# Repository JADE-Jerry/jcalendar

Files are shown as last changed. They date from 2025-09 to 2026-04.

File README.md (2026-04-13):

# J-Calendar
墨水屏日历，采用三色4.2寸墨水屏，展示基本月历信息，支持农历、公共假期、倒计日、天气（实时天气、每日天气）、课程表展示。<br>
项目以低难度、低成本的方式，方便爱好者实现属于自己的低功耗月历。<br>
<br>
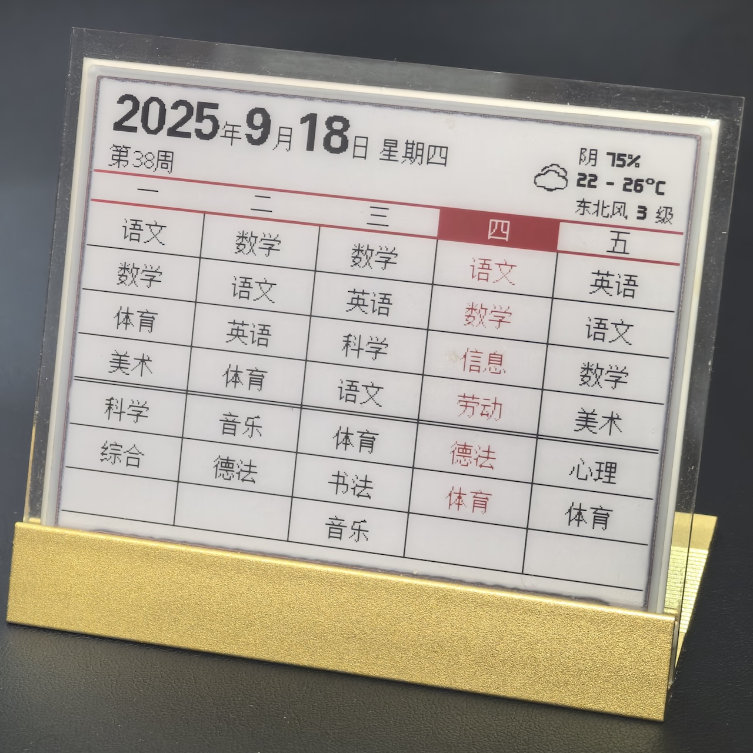
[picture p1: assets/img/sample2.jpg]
<br>
Bilibili连接：https://www.bilibili.com/video/BV1wHDhYoE3G/<br>
注：固件仅供个人下载免费使用，禁止商用。

## Prepare & Meterial
1. esp32开发板(建议lolin32 lite,其他esp32开发板亦可)<br>
2. 4.2寸三色墨水屏(400*300)。
3. 通用墨水屏驱动板。
4. 锂电池,需要做ph2.0接头，建议购买带保护板的电池。(推荐603048, 900mah)
5. 金属底座亚克力台卡,95*80mm。
6. 轻触开关,(12\*12\*7.3,带键帽)
7. 工具:电烙铁、电线若干。

## Manufacture Guide:
1. 开发板接线<br>
    * 墨水屏驱动板
        * Busy->4
        * RST->16
        * DC->17
        * CS->5
        * SCK->18
        * SDA->23
        * GND->GND
        * VCC->3V
    * 其他
        * 按钮->(PIN_14, GND)
        * LED->22(板载)
        * 电池ADC->32
2. 三色墨水屏排线插入时注意针脚方向,屏幕排线和驱动板排线1号针脚均是悬空,注意对齐。
3. 电池接口需要是ph2.0,且注意正负极(开发板上有标注),如果电池的正负极反了,可以用镊子调整电池插头。
    1. 可选：电池电压检测电路，需要通过两个相同的大电阻（建议500K以上）串联，通过分压进行检测电池电压。如图
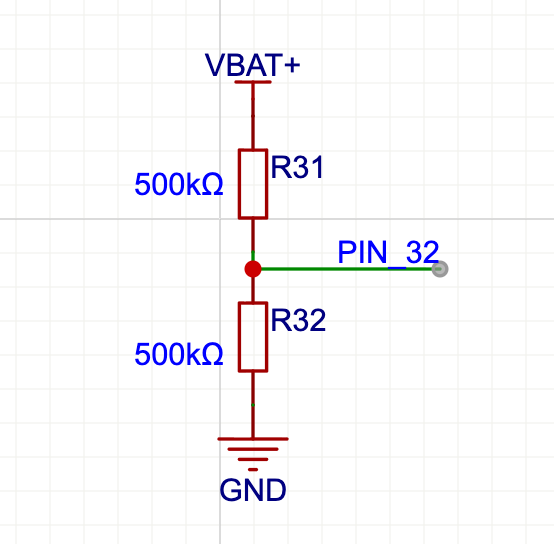
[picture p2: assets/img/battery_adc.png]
    <br>
4. 烧录固件<br>
    使用ESP32的烧录工具flash_download_tool烧录固件. [Flash Download Tools](https://www.espressif.com/en/support/download/other-tools?keys=flash+download+tools)
    1. 选择烧录的文件和烧录地址（bootloader.bin与partitions.bin烧录过一次后，就不需要重复烧录了）
    2. 选择Flash的配置信息
    3. 选择连接的串口以及波特率（波特率可以根据实际情况调整）
    4. 擦除Flash。
    5. 开始烧录。<br>
    <span style="color:red">注：文件前面一定要打勾，否则不会刷进flash的！！！</span><br>
    （参考下图）<br>
    
5. 安装盒，3D打印，用PLA或ABS均可。[E-ink box2 v22.3mf](./assets/file/E-ink%20box2%20v22.3mf)

## Button Operation Guide:
1. **单点**  
    如果处在休眠中,唤醒系统,并刷新月历。
    如果处在运行中,强制刷新/切换日历。
    如果处在配置中,不做任何处理。
2. **双击**  
    系统正常运行中,双击进入系统配置。(并强制停止WIFI相关操作,如获取天气。)
    系统配置状态中,双击重启系统。
3. **长按**  
    系统运行中,长按清除配置信息(WIFI密钥除外)和缓存,并重启。

## LED Indicator: 
(板载LED,PIN-22)
1. 快闪: LED每秒闪约两次，系统启动中(正在连接WIFI)
2. 常亮: WIFI连接完成。
3. 慢闪: LED每两秒闪一次，WIFI连接失败（10秒钟后休眠）。
4. 三短闪一长灭: 系统配置中。（3分钟后超时休眠）
5. 熄灭: 系统休眠。

## Web Config Guide:
通过在开机状态下(LED常亮)双击,即可进入配置状态,这时系统会生成一个名为J-Calendar的ap,默认密码为:password。(默认超时时间为180秒)
连接上ap后会直接弹出配置页面。(或者直接通过浏览器输入地址 http://192.168.4.1进入)。
配置页面:
1. Config Wifi. Wifi配置  
    进入配置wifi页面,选择搜索到的ap,并输入密码,并保存。
2. Setup. 系统配置  
    * 周首日:
        * 0: 周日(默认); 1: 周一;
    * 和风天气:
        * 和风天气Host：输入在和风天气Host。（例如：******.re.qweatherapi.com, 具体值在自己的和风天气控制台可以查到<br>
        * 输入和风天气的API Key：输入和风天气Key。（如果Key置空,天气将不会被刷新。）<br>
        * 天气类型：0:每日天气（默认，每天凌晨刷新一次）; 1: 实时天气(每两个小时刷新一次天气)<br>
        * 位置ID：城市id或者经纬度 例1: 101010100 例2: 116.41,39.92 <br>
        [城市id列表](./assets/file/China-City-List-latest.csv) <br>
    * 倒数日:<br>输入倒数日名称和日期,名称不能超过4个中文字符,时间以yyyyMMdd的格式填入。配置正确的话,日历每天会显示倒数“距****还有**天”。如果倒数日名称为空,系统将不显示倒数日信息。
    * 日期Tag:<br>
        1. 输入格式，yyyyMMddx，yyyy为年，每年显示设为0000，MM为月份，每月显示设为00，dd为日期，x为tag的图标（a:书签；b：金钱；c：笑脸；d：警告）。例如：00000015b，每年每月15日旁边显示$符号；00000312a，每年3月12日，显示书签符号。
        2. 最多可以设置三个tag，中间以分号隔开。例如：00000015b;00000312a
    * 课程表:<br>
        输入格式，分多段，每段用“；”隔开。
        1. 课程数段。"000"，三位数字，分别代表上午、下午、晚上课程数，不可省略。如：“430”，代表上午4课，下午三课，晚上无课。
        2. 每日课程（多段）。首位为星期数，后接当日的课程，以“，”分隔。如：“二,数学,语文,英语,体育,音乐,德法,”，表示周二的课程为数学、语文...等。
        3. 样例: 430;一,语文,数学,体育,美术,科学,综合;二,数学,语文,英语,体育,音乐,德法;三,数学,英语,科学,语文,体育,书法,音乐;四,语文,数学,信息,劳动,德法,体育;五,英语,语文,数学,美术,心理,体育;
        4. 注意：分隔用的“,”“;”，必须为英文符号，不可用中文符号。
    * 保存配置后，系统自动重启。
3. Update. OTA升级  
    此项需要在浏览器内完成,通过ip地址访问配置页面,然后进入Update,选择固件文件后上传,等待。刷新完成后,页面会有成功提示。
4. Restart. 重启  
    在所有配置完后,需要重启生效。(也可以在配置状态下,双击按钮重启)
5. Info. 系统信息
    可以监控系统的硬件情况,也可以在里面清除配置的Wifi密钥。
6. Exit. 退出  
    退出配置状态。

## Q & A
1. Q: 刷完机后，如何配置？启动流程是如何的？<br>
A: 需要在系统运行状态下（状态灯常亮或慢闪时）双击按键，即可进入配置状态。LED灯变成三短闪一长灭时说明进入配置状态了。
2. Q: 刷完机后，没有反应该如何处理？<br>
A: 观察22针脚的LED是否点亮，有闪烁说明固件已经刷入，如果没有闪烁可以尝试点击重置按钮重启，或者拔掉电源线和usb线，重插来重启。此外，还可使用串口工具通过usb的com口获取启动日志来进一步确认故障原因。
3. Q: 可以支持哪种屏？<br>
A: 仅4.2寸三色屏(目前仅支持黑白红,将来支持黑白黄)。
4. Q: 我使用的屏应该烧录哪个固件？<br>
A: 从经验上预估，大部分比较新一些的选1680，新一点的拆机屏选z98。SES的拆机屏选z21，如果是非常老的屏，选z15。实在不行的话，三个固件都刷一遍试试。<br>
明确的丝印对应如下：<br>
    |丝印|固件|
    |-----|-----|
    |P420010|1680|
    |E042A43-A0|z98|
    |A13600**|z21|
5. Q: 使用flash download tool刷新固件时，报错，连接串口失败。<br>
A: 1. 检查USB线连接是否正常。 <br>2. app的串口下拉框里是否检测到COM口。 <br>3. 把其他串口工具关闭，防止占用COM口。
6. Q: 刷新固件的过程中提示报错。<br>
A: 1. 换根质量较好的或短一些的USB线，或换个USB口插入。 <br>2. 可以将刷新的波特率降低一点，如选择速率低一点的115200。
7. Q: 刷新固件后，需要重新配置吗？<br>
A: 仅刷新app固件后，配置是保留的，所以，无需重新配置。如果刷新了分区表partition.bin，会将esp的nvs区刷新，这时候需要重新配置。
8. Q: 填入和风天气的API Key和位置ID后，没有成功获取天气信息。<br>
A: 2025年3月1日后注册的和风天气账户有API Host限制，请下载1.0.25以后版本，在配置时配置API Host信息。
8. Q: 如何切换日历和课程表显示？<br>
A: 在系统运行状态下(状态灯常亮)，单击按键，稍等即可切换课程表的展示。
9. Q: 充一次电能使用多久？<br>
A: 这个取决于选用的电池和使用场景，以及开发板的质量。正常情况下休眠的电流为120ua左右，刷新一次需要1.6mah。以900mah的电池、每日刷新一次举例，理论上大概可以待机半年。
10. Q: 为何我的日历待机时间很短？<br>
A: 可能是开发板或驱动板的质量问题，实际发现有些板子休眠功耗能达2ma，这会极大影响待机时长。另外，由于电池容量的虚标，待机时长与理论计算值也有较大偏差。建议，增加电池测量电路，及时显示电池电量情况。

## Releases
### 1.1.9
* Fix: z98等版本编译问题。
### 1.1.8
* Fix: 农历日历错误。
### 1.1.7
* Fix: 内置节日信息未展现。
### 1.1.6
* Fix: 课程表页面星期显示位置不当。
### 1.1.5
* Fix: 将1680驱动加入GxEPD2,并放入项目的lib目录。 
### 1.1.4
* Refine: 电池检测、功耗优化
* New: 增加1680驱动版本
### 1.1.3
* Fix: some bugs.
### 1.1.2
* Refine: 功耗
### 1.1.1
* New Featue: 增加对电池的测量和显示。
### 1.1.0
* New Feature: 课程表。
* Refine: 对针脚统一配置。
* Fix: some bugs.
### 1.0.27
* Fix: 闰月错误。（bug from nongli lib）
### 1.0.26
* Refine: 显示当前为第**周。（国际标准（ISO 8601）‌：以周一作为每周起始日）
### 1.0.25
* Fix: 和风天气api变更，需要输入API Host（在配置页面增加配置项）
### 1.0.24
* Refine: 配置页面location约束改为64长度，允许输入经纬度设置天气位置（e.g. 116.41,39.92）
### 1.0.23
* Refine: 修改和风天气请求url。
* Fix: bug(获取holiday返回码)。
### 1.0.22
* 项目开源：此项目使用GNU General Public License v3.0许可证授权。详情请参阅LICENSE文件。
* Refine：农历计算功能移出。（农历功能作为独立库，以MIT协议开源）
### 1.0.21
* Fix: bug (wrong background color of calender header).
### 1.0.20
* Fix: bugs.
### 1.0.19
* New: 假日信息通过网络API获取。
* Refine: 由于esp32内置时钟的误差，会有可能唤醒的时间不准确，同时，由于处于午夜0点左右，导致提前刷新或在刷新期间切换日期，导致日期显示不准确。处理方式：计时器唤醒的情况下，23:50以后不刷新直接休眠，等待至0点以后唤醒刷新。
### 1.0.18
* Fix: 修正Wifi连接失败后，同步时间导致系统时间错误。
### 1.0.17
* Refine: 如果wifi连接失败，等待10s再休眠，并增加LED慢闪作为指示。（在这时间段内供用户进行双击打开配置状态）
* Fix: 修正倒数日名称显示不足的问题。
### 1.0.16
* New Feature: UI调整，新增今日农历日期的展现。
### 1.0.15
* Fix: 编译异常。
### 1.0.14
* Fix: bug(假日颜色不正确), 增加显示假日和调休icon(日历右上角)。
### 1.0.13
* Fix: bugs.
### 1.0.12
* 新功能：增加设置每周首日，默认首日为周日。
### 1.0.11
* 优化：补充部分公历&农历节日
### 1.0.10
* 新功能：增加日期Tag（通过配置页面进行配置）
### 1.0.9
* 优化：
    1. 统一每日天气与实时天气的布局。
    2. 增加时间容错性，当同步网络时间失败的时候，使用天气api的更新时间。
* 新功能：增加节日显示（元旦、劳动节、国庆节）
### 1.0.8
* 优化显示：加粗当前日期框；不再使用局刷，全部改为全屏刷新（提高显示的清晰度，兼容不支持局部刷新的三色屏）。
* 预置2025年公休假信息。
### 1.0.7
* 增加24节气显示。修复部分bug。
### 1.0.6
* 增加天气模式--*每日天气*（默认配置），每天刷新一次。（增加月历待机时长。部分不支持局刷的屏可以选择这个模式。）
### 1.0.5 
* 增加强制刷新处理(单击按钮)。
* 修复日历功能、修复日历字典数据
* 修复部分bug。
### 1.0.4<br>
* 增加倒计日功能
* 修复部分bug。
### 1.0.3
* 基本功能
* 功耗优化等

## License
此项目使用GNU General Public License v3.0许可证授权。详情请参阅LICENSE文件。

### ★★★固件还不错，支持一下★★★

<br>

感谢大家的赞助：
\*1，\*翔，\*菜，\*华，\*名，\*波, \*人, G\*n。

## Reference:
1. \<WEMOS LOLIN32簡介\> https://swf.com.tw/?p=1331&cpage=1
2. \<GxEPD2\> https://github.com/ZinggJM/GxEPD2
3. \<U8g2_for_Adafruit_GFX\> https://github.com/olikraus/U8g2_for_Adafruit_GFX
4. \<和风天气\> https://dev.qweather.com/docs/api/weather/weather-now/
<br>
 Copyright © 2023-2026. All Rights Reserved.

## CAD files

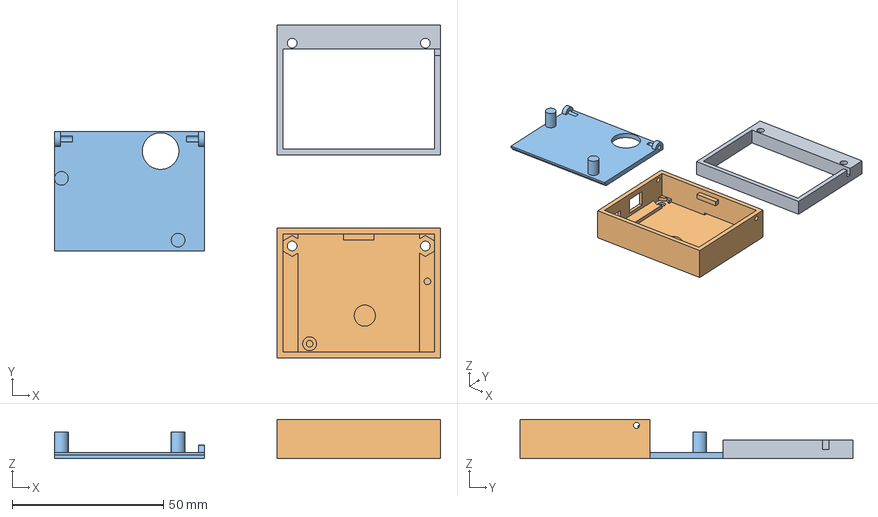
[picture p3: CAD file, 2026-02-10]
assets/file/E-ink box2 v22.3mf
127.5 x 110.0 x 13.0 mm
零部件3
零部件1
实体1.stl

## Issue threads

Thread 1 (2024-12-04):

关于自动刷新的问题

SzetoFZ, 2024-12-04:
由于开启了自动两小时的自动刷新，当正在刷新时出现无法正常联网的情况下会自动随机刷新一个任何时间的日期，能不能修改一下当刷新时无法联网的时可以保留之前的日期的功能

JADE-Jerry, 2024-12-04:
你刷的是哪个版本。最新的版本已经处理过这个问题，如果无法联网的话，时间会根据单片机内部时间来计算当下时间，但是会有大概每天20秒左右的误差。

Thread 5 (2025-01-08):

1.0.14，刷完z98固件，power on后立即power off，屏幕没变化。

ahptc6188, 2025-01-08:
09:47:39.202 -> Calendar Show Time: 2006-05-26 16:25:28
09:47:39.202 -> [Task] screen update begin...
09:47:39.293 -> Invalid countdown-day parameters.
**09:47:39.293 -> _PowerOn : 25
09:47:39.466 -> _Update_Full : 1
09:47:39.466 -> _PowerOff : 1
09:47:39.466 -> _PowerOff : 1**
09:47:39.466 -> [Task] screen update end...
09:47:39.507 -> [   422][E][Preferences.cpp:483] getString(): nvs_get_str len fail: QWEATHER_KEY NOT_FOUND

JADE-Jerry, 2025-01-08:
要么是屏幕连接不好，要么是驱动不对，建议换固件。

Closed 2025-01-08.

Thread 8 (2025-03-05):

通电或配置时，频繁自动重启

funcc, 2025-03-05:
刚通电或进行配置时，板子经常频繁重启，多的时候半小时都在不停重启。用串口连上看，提示
***********************
      J-Calendar
    version: 1.0.22
***********************

Copyright © 2022-2025 JADE Software Co., Ltd. All Rights Reserved.

Wm begin...
*wm:AutoConnect
*wm:Connecting to SAVED AP: xxxx
*wm:AutoConnect: SUCCESS
*wm:STA IP Address: 192.168.0.178
Connect OK.
[Task] get weather begin...
Weather Type: 0
               decompressed 1666 bytes
[Task] get weather end...
SNTP OK.
Now: 2025-03-05 22:52:14
Wifi closed after data fetch.
System Time: 2025-03-05 22:52:14
                                Calendar Show Time: 2025-03-05 22:52:14
                                                                       [Task] screen update begin...
Busy Timeout!
_PowerOn : 40001203

Error reading data on serial port:
  Access is denied.

funcc, 2025-03-06:
可能是屏有问题，虽然有时能正常。换块屏就没问题了。

Closed 2025-03-06.

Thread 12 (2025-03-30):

ESP32-C3编译报错

TopPeak-Xiang, 2025-03-30:
# ESP32-C3编译报错
> 在使用源文件中自带ESP32 C3的环境进行编译下载时出现了下面的问题，此问题出现在API.hpp文件中：

```c++
no matching function for call to 'ArduinoUZlib::decompress(uint8_t*, uint32_t, uint8_t*&, size_t&)'
```

> 下面是输出的信息：

```c++
*  正在执行任务: C:\Users\Cheems\.platformio\penv\Scripts\platformio.exe run --target upload --environment esp32c3

Processing esp32c3 (platform: espressif32; board: esp32-c3-devkitm-1; framework: arduino)
---------------------------------------------------------------------------------------------------------------------------------------
Verbose mode can be enabled via `-v, --verbose` option
CONFIGURATION: https://docs.platformio.org/page/boards/espressif32/dfrobot_beetle_esp32c3.html
PLATFORM: Espressif 32 (6.10.0) > DFRobot Beetle ESP32-C3
HARDWARE: ESP32C3 160MHz, 320KB RAM, 4MB Flash
DEBUG: Current (cmsis-dap) External (cmsis-dap, esp-bridge, esp-builtin, esp-prog, iot-bus-jtag, jlink, minimodule, olimex-arm-usb-ocd, olimex-arm-usb-ocd-h, olimex-arm-usb-tiny-h, olimex-jtag-tiny, tumpa)
PACKAGES:
 - framework-arduinoespressif32 @ 3.20017.241212+sha.dcc1105b
 - tool-esptoolpy @ 1.40501.0 (4.5.1)
 - tool-mkfatfs @ 2.0.1
 - tool-mklittlefs @ 1.203.210628 (2.3)
 - tool-mkspiffs @ 2.230.0 (2.30)
 - toolchain-riscv32-esp @ 8.4.0+2021r2-patch5
LDF: Library Dependency Finder -> https://bit.ly/configure-pio-ldf
LDF Modes: Finder ~ chain, Compatibility ~ soft
Found 42 compatible libraries
Scanning dependencies...
Dependency Graph
|-- GxEPD2 @ 1.6.3
|-- U8g2_for_Adafruit_GFX @ 1.8.0
|-- ArduinoJson @ 7.3.1
|-- WiFiManager @ 2.0.17
|-- OneButton @ 2.6.1
|-- Nongli @ 1.0.0+sha.6d00195
|-- ArduinoUZlib @ 0.0.1+sha.20aff95
|-- WiFi @ 2.0.0
|-- HTTPClient @ 2.0.0
|-- HTTPUpdate @ 2.0.0
|-- Preferences @ 2.0.0
Building in release mode
Compiling .pio\build\esp32c3\src\_sntp.cpp.o
Compiling .pio\build\esp32c3\src\main.cpp.o
Compiling .pio\build\esp32c3\src\screen_ink.cpp.o
Compiling .pio\build\esp32c3\src\weather.cpp.o
Archiving .pio\build\esp32c3\lib8aa\libWire.a
Archiving .pio\build\esp32c3\libc98\libSPI.a
Indexing .pio\build\esp32c3\lib8aa\libWire.a
Indexing .pio\build\esp32c3\libc98\libSPI.a
Archiving .pio\build\esp32c3\lib466\libAdafruit BusIO.a
Archiving .pio\build\esp32c3\libf7d\libAdafruit GFX Library.a
Indexing .pio\build\esp32c3\lib466\libAdafruit BusIO.a
Indexing .pio\build\esp32c3\libf7d\libAdafruit GFX Library.a
Compiling .pio\build\esp32c3\libcfb\GxEPD2\GxEPD2_EPD.cpp.o
Compiling .pio\build\esp32c3\libcfb\GxEPD2\epd3c\GxEPD2_1248c.cpp.o
Compiling .pio\build\esp32c3\libcfb\GxEPD2\epd3c\GxEPD2_154_Z90c.cpp.o
Compiling .pio\build\esp32c3\libcfb\GxEPD2\epd3c\GxEPD2_154c.cpp.o
Compiling .pio\build\esp32c3\libcfb\GxEPD2\epd3c\GxEPD2_213_Z19c.cpp.o
Compiling .pio\build\esp32c3\libcfb\GxEPD2\epd3c\GxEPD2_213_Z98c.cpp.o
Compiling .pio\build\esp32c3\libcfb\GxEPD2\epd3c\GxEPD2_213c.cpp.o
Compiling .pio\build\esp32c3\libcfb\GxEPD2\epd3c\GxEPD2_266c.cpp.o
Compiling .pio\build\esp32c3\libcfb\GxEPD2\epd3c\GxEPD2_270c.cpp.o
Compiling .pio\build\esp32c3\libcfb\GxEPD2\epd3c\GxEPD2_290_C90c.cpp.o
Compiling .pio\build\esp32c3\libcfb\GxEPD2\epd3c\GxEPD2_290_Z13c.cpp.o
Compiling .pio\build\esp32c3\libcfb\GxEPD2\epd3c\GxEPD2_290c.cpp.o
In file included from src/_sntp.cpp:7:
src/API.hpp: In member function 'bool API<MAX_RETRY>::getRestfulAPI(String, API<MAX_RETRY>::callback, API<MAX_RETRY>::precall)':
src/API.hpp:110:107: error: no matching function for call to 'ArduinoUZlib::decompress(uint8_t*, uint32_t, uint8_t*&, size_t&)'
                         ArduinoUZlib::decompress((uint8_t*)s.c_str(), (uint32_t)s.length(), outBuf, outLen);
                                                                                                           ^
In file included from src/API.hpp:9,
                 from src/_sntp.cpp:7:
.pio/libdeps/esp32c3/ArduinoUZlib/src/ArduinoUZlib.h:10:20: note: candidate: 'static int32_t ArduinoUZlib::decompress(uint8_t*, uint32_t, uint8_t*&, uint32_t&)' <near match>
     static int32_t decompress(uint8_t *in_buf, uint32_t in_size, uint8_t *&dest, uint32_t &out_size);
                    ^~~~~~~~~~
.pio/libdeps/esp32c3/ArduinoUZlib/src/ArduinoUZlib.h:10:20: note:   conversion of argument 4 would be ill-formed:
*** [.pio\build\esp32c3\src\_sntp.cpp.o] Error 1
In file included from include/weather.h:4,
                 from src/main.cpp:10:
src/API.hpp: In member function 'bool API<MAX_RETRY>::getRestfulAPI(String, API<MAX_RETRY>::callback, API<MAX_RETRY>::precall)':
src/API.hpp:110:107: error: no matching function for call to 'ArduinoUZlib::decompress(uint8_t*, uint32_t, uint8_t*&, size_t&)'
                         ArduinoUZlib::decompress((uint8_t*)s.c_str(), (uint32_t)s.length(), outBuf, outLen);
                                                                                                           ^
In file included from src/API.hpp:9,
                 from include/weather.h:4,
                 from src/main.cpp:10:
.pio/libdeps/esp32c3/ArduinoUZlib/src/ArduinoUZlib.h:10:20: note: candidate: 'static int32_t ArduinoUZlib::decompress(uint8_t*, uint32_t, uint8_t*&, uint32_t&)' <near match>
     static int32_t decompress(uint8_t *in_buf, uint32_t in_size, uint8_t *&dest, uint32_t &out_size);
                    ^~~~~~~~~~
.pio/libdeps/esp32c3/ArduinoUZlib/src/ArduinoUZlib.h:10:20: note:   conversion of argument 4 would be ill-formed:
In file included from include/weather.h:4,
                 from src/screen_ink.cpp:3:
src/API.hpp: In member function 'bool API<MAX_RETRY>::getRestfulAPI(String, API<MAX_RETRY>::callback, API<MAX_RETRY>::precall)':
src/API.hpp:110:107: error: no matching function for call to 'ArduinoUZlib::decompress(uint8_t*, uint32_t, uint8_t*&, size_t&)'
                         ArduinoUZlib::decompress((uint8_t*)s.c_str(), (uint32_t)s.length(), outBuf, outLen);
                                                                                                           ^
In file included from src/API.hpp:9,
                 from include/weather.h:4,
                 from src/screen_ink.cpp:3:
.pio/libdeps/esp32c3/ArduinoUZlib/src/ArduinoUZlib.h:10:20: note: candidate: 'static int32_t ArduinoUZlib::decompress(uint8_t*, uint32_t, uint8_t*&, uint32_t&)' <near match>
     static int32_t decompress(uint8_t *in_buf, uint32_t in_size, uint8_t *&dest, uint32_t &out_size);
                    ^~~~~~~~~~
.pio/libdeps/esp32c3/ArduinoUZlib/src/ArduinoUZlib.h:10:20: note:   conversion of argument 4 would be ill-formed:
In file included from include/weather.h:4,
                 from src/weather.cpp:1:
src/API.hpp: In member function 'bool API<MAX_RETRY>::getRestfulAPI(String, API<MAX_RETRY>::callback, API<MAX_RETRY>::precall)':
src/API.hpp:110:107: error: no matching function for call to 'ArduinoUZlib::decompress(uint8_t*, uint32_t, uint8_t*&, size_t&)'
                         ArduinoUZlib::decompress((uint8_t*)s.c_str(), (uint32_t)s.length(), outBuf, outLen);
                                                                                                           ^
In file included from src/API.hpp:9,
                 from include/weather.h:4,
                 from src/weather.cpp:1:
.pio/libdeps/esp32c3/ArduinoUZlib/src/ArduinoUZlib.h:10:20: note: candidate: 'static int32_t ArduinoUZlib::decompress(uint8_t*, uint32_t, uint8_t*&, uint32_t&)' <near match>
     static int32_t decompress(uint8_t *in_buf, uint32_t in_size, uint8_t *&dest, uint32_t &out_size);
                    ^~~~~~~~~~
.pio/libdeps/esp32c3/ArduinoUZlib/src/ArduinoUZlib.h:10:20: note:   conversion of argument 4 would be ill-formed:
*** [.pio\build\esp32c3\src\main.cpp.o] Error 1
*** [.pio\build\esp32c3\src\screen_ink.cpp.o] Error 1
*** [.pio\build\esp32c3\src\weather.cpp.o] Error 1
================================================= [FAILED] Took 8.35 seconds =================================================

Environment    Status    Duration
-------------  --------  ------------
esp32c3        FAILED    00:00:08.349
============================================ 1 failed, 0 succeeded in 00:00:08.349 ============================================

 *  终端进程“C:\Users\Cheems\.platformio\penv\Scripts\platformio.exe 'run', '--target', 'upload', '--environment', 'esp32c3'”已终止，退出代码: 1。
 *  终端将被任务重用，按任意键关闭。
```

JADE-Jerry, 2025-04-21:
暂未考虑支持esp32c3，不过欢迎pull request。

Closed 2025-04-21.

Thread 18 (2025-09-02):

gpiz解压内存泄漏

fengtao918, 2025-09-02:
ArduinoUZlib::decompress((uint8_t*)s.c_str(), (uint32_t)s.length(), outBuf, outLen);
ArduinoUZlib::decompress内部通过malloc分配内存，没有free。
esp32进入深度睡眠再次唤醒后是否会重置系统从而消除内存泄漏的影响。

Closed 2025-09-05.

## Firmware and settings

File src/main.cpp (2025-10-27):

#include <Arduino.h>
#include <ArduinoJson.h>

#include <WiFiManager.h>

#include "esp_sleep.h"

#include <wiring.h>

#include "battery.h"

#include "led.h"
#include "_sntp.h"
#include "weather.h"
#include "screen_ink.h"
#include "_preference.h"

#include "version.h"

#include "OneButton.h"
OneButton button(KEY_M, true);

void IRAM_ATTR checkTicks() {
    button.tick();
}

WiFiManager wm;
WiFiManagerParameter para_qweather_host("qweather_host", "和风天气Host", "", 64); //     和风天气key
WiFiManagerParameter para_qweather_key("qweather_key", "和风天气API Key", "", 32); //     和风天气key
// const char* test_html = "<br/><label for='test'>天气模式</label><br/><input type='radio' name='test' value='0' checked> 每日天气test </input><input type='radio' name='test' value='1'> 实时天气test</input>";
// WiFiManagerParameter para_test(test_html);
WiFiManagerParameter para_qweather_type("qweather_type", "天气类型（0:每日天气，1:实时天气）", "0", 2, "pattern='\\[0-1]{1}'"); //     城市code
WiFiManagerParameter para_qweather_location("qweather_loc", "位置ID", "", 64); //     城市code
WiFiManagerParameter para_cd_day_label("cd_day_label", "倒数日（4字以内）", "", 10); //     倒数日
WiFiManagerParameter para_cd_day_date("cd_day_date", "日期（yyyyMMdd）", "", 8, "pattern='\\d{8}'"); //     城市code
WiFiManagerParameter para_tag_days("tag_days", "日期Tag（yyyyMMddx，详见README）", "", 30); //     日期Tag
WiFiManagerParameter para_si_week_1st("si_week_1st", "每周起始（0:周日，1:周一）", "0", 2, "pattern='\\[0-1]{1}'"); //     每周第一天
WiFiManagerParameter para_study_schedule("study_schedule", "课程表", "0", 4000, "pattern='\\[0-9]{3}[;]$'"); //     每周第一天

void print_wakeup_reason() {
    esp_sleep_wakeup_cause_t wakeup_reason = esp_sleep_get_wakeup_cause();
    switch (wakeup_reason) {
    case ESP_SLEEP_WAKEUP_EXT0:
        Serial.println("Wakeup caused by external signal using RTC_IO");
        break;
    case ESP_SLEEP_WAKEUP_EXT1:
    {
        Serial.println("Wakeup caused by external signal using RTC_CNTL");
        uint64_t status = esp_sleep_get_ext1_wakeup_status();
        if (status == 0) {
            Serial.println(" *None of the configured pins woke us up");
        } else {
            Serial.print(" *Wakeup pin mask: ");
            Serial.printf("0x%016llX\r\n", status);
            for (int i = 0; i < 64; i++) {
                if ((status >> i) & 0x1) {
                    Serial.printf("  - GPIO%d\r\n", i);
                }
            }
        }
        break;
    }
    case ESP_SLEEP_WAKEUP_TIMER:
        Serial.println("Wakeup caused by timer");
        break;
    case ESP_SLEEP_WAKEUP_TOUCHPAD:
        Serial.println("Wakeup caused by touchpad");
        break;
    case ESP_SLEEP_WAKEUP_ULP:
        Serial.println("Wakeup caused by ULP program");
        break;
    default:
        Serial.printf("Wakeup was not caused by deep sleep.\r\n");
    }
}

void buttonClick(void* oneButton);
void buttonDoubleClick(void* oneButton);
void buttonLongPressStop(void* oneButton);
void go_sleep();

unsigned long _idle_millis;
unsigned long TIME_TO_SLEEP = 180 * 1000;

bool _wifi_flag = false;
unsigned long _wifi_failed_millis;
void setup() {
    delay(10);
    Serial.begin(115200);
    Serial.println(".");
    print_wakeup_reason();
    Serial.println("\r\n\r\n");
    delay(10);


    Serial.printf("***********************\r\n");
    Serial.printf("      J-Calendar\r\n");
    Serial.printf("    version: %s\r\n", J_VERSION);
    Serial.printf("***********************\r\n\r\n");
    Serial.printf("Copyright © 2022-2025 JADE Software Co., Ltd. All Rights Reserved.\r\n\r\n");

    led_init();
    led_on();
    delay(100);
    int voltage = readBatteryVoltage();
    Serial.printf("Battery: %d mV\r\n", voltage);
    if(voltage < 2500) {
        Serial.println("[INFO]电池损坏或无ADC电路。");
    } else if(voltage < 3000) {
        Serial.println("[WARN]电量低于3v，系统休眠。");
        go_sleep();
    } else if (voltage < 3300) {
        // 低于3.3v，电池电量用尽，屏幕给警告，然后关机。 
        Serial.println("[WARN]电量低于3.3v，警告并系统休眠。");
        si_warning("电量不足，请充电！");
        go_sleep();
    } else if (voltage > 4400) {
        Serial.println("[INFO]未接电池。");
    }

    button.setClickMs(300);
    button.setPressMs(3000); // 设置长按的时长
    button.attachClick(buttonClick, &button);
    button.attachDoubleClick(buttonDoubleClick, &button);
    // button.attachMultiClick()
    button.attachLongPressStop(buttonLongPressStop, &button);
    attachInterrupt(digitalPinToInterrupt(KEY_M), checkTicks, CHANGE);

    Serial.println("Wm begin...");
    led_fast();
    wm.setHostname("J-Calendar");
    wm.setEnableConfigPortal(false);
    wm.setConnectTimeout(10);
    if (wm.autoConnect()) {
        Serial.println("Connect OK.");
        led_on();
        _wifi_flag = true;
    } else {
        Serial.println("Connect failed.");
        _wifi_flag = false;
        _wifi_failed_millis = millis();
        led_slow();
        _sntp_exec(2);
        weather_exec(2);
        WiFi.mode(WIFI_OFF); // 提前关闭WIFI，省电
        Serial.println("Wifi closed.");
    }
}

/**
 * 处理各个任务
 * 1. sntp同步
 *      前置条件：Wifi已连接
 * 2. 刷新日历
 *      前置条件：sntp同步完成（无论成功或失败）
 * 3. 刷新天气信息
 *      前置条件：wifi已连接
 * 4. 系统配置
 *      前置条件：无
 * 5. 休眠
 *      前置条件：所有任务都完成或失败，
 */
void loop() {
    button.tick(); // 单击，刷新页面；双击，打开配置；长按，重启
    wm.process();
    // 前置任务：wifi已连接
    // sntp同步
    if (_sntp_status() == -1) {
        _sntp_exec();
    }
    // 如果是定时器唤醒，并且接近午夜（23:50之后），则直接休眠
    if (_sntp_status() == SYNC_STATUS_TOO_LATE) {
        go_sleep();
    }
    // 前置任务：wifi已连接
    // 获取Weather信息
    if (weather_status() == -1) {
        weather_exec();
    }

    // 刷新日历
    // 前置任务：sntp、weather
    // 执行条件：屏幕状态为待处理
    if (_sntp_status() > 0 && weather_status() > 0 && si_screen_status() == -1) {
        // 数据获取完毕后，关闭Wifi，省电
        if (!wm.getConfigPortalActive()) {
            WiFi.mode(WIFI_OFF);
        }
        Serial.println("Wifi closed after data fetch.");

        si_screen();
    }

    // 休眠
    // 前置条件：屏幕刷新完成（或成功）

    // 未在配置状态，且屏幕刷新完成，进入休眠
    if (!wm.getConfigPortalActive() && si_screen_status() > 0) {
        if (_wifi_flag) {
            go_sleep();
        }
        if (!_wifi_flag && millis() - _wifi_failed_millis > 10 * 1000) { // 如果wifi连接不成功，等待10秒休眠
            go_sleep();
        }
    }
    // 配置状态下，
    if (wm.getConfigPortalActive() && millis() - _idle_millis > TIME_TO_SLEEP) {
        go_sleep();
    }

    delay(10);
}


// 刷新页面
void buttonClick(void* oneButton) {
    Serial.println("Button click.");
    if (wm.getConfigPortalActive()) {
        Serial.println("In config status.");
    } else {
        Serial.println("Refresh screen manually.");
        Preferences pref;
        pref.begin(PREF_NAMESPACE);
        int _si_type = pref.getInt(PREF_SI_TYPE);
        pref.putInt(PREF_SI_TYPE, _si_type == 0 ? 1 : 0);
        pref.end();
        si_screen();
    }
}

void saveParamsCallback() {
    Preferences pref;
    pref.begin(PREF_NAMESPACE);
    pref.putString(PREF_QWEATHER_HOST, para_qweather_host.getValue());
    pref.putString(PREF_QWEATHER_KEY, para_qweather_key.getValue());
    pref.putString(PREF_QWEATHER_TYPE, strcmp(para_qweather_type.getValue(), "1") == 0 ? "1" : "0");
    pref.putString(PREF_QWEATHER_LOC, para_qweather_location.getValue());
    pref.putString(PREF_CD_DAY_LABLE, para_cd_day_label.getValue());
    pref.putString(PREF_CD_DAY_DATE, para_cd_day_date.getValue());
    pref.putString(PREF_TAG_DAYS, para_tag_days.getValue());
    pref.putString(PREF_SI_WEEK_1ST, strcmp(para_si_week_1st.getValue(), "1") == 0 ? "1" : "0");
    pref.putString(PREF_STUDY_SCHEDULE, para_study_schedule.getValue());
    pref.end();

    Serial.println("Params saved.");

    _idle_millis = millis(); // 刷新无操作时间点

    ESP.restart();
}

void preSaveParamsCallback() {
}

// 双击打开配置页面
void buttonDoubleClick(void* oneButton) {
    Serial.println("Button double click.");
    if (wm.getConfigPortalActive()) {
        ESP.restart();
        return;
    }

    if (weather_status == 0) {
        weather_stop();
    }

    // 设置配置页面
    // 根据配置信息设置默认值
    Preferences pref;
    pref.begin(PREF_NAMESPACE);
    String qHost = pref.getString(PREF_QWEATHER_HOST);
    String qToken = pref.getString(PREF_QWEATHER_KEY);
    String qType = pref.getString(PREF_QWEATHER_TYPE, "0");
    String qLoc = pref.getString(PREF_QWEATHER_LOC);
    String cddLabel = pref.getString(PREF_CD_DAY_LABLE);
    String cddDate = pref.getString(PREF_CD_DAY_DATE);
    String tagDays = pref.getString(PREF_TAG_DAYS);
    String week1st = pref.getString(PREF_SI_WEEK_1ST, "0");
    String studySchedule = pref.getString(PREF_STUDY_SCHEDULE);
    pref.end();

    para_qweather_host.setValue(qHost.c_str(), 64);
    para_qweather_key.setValue(qToken.c_str(), 32);
    para_qweather_location.setValue(qLoc.c_str(), 64);
    para_qweather_type.setValue(qType.c_str(), 1);
    para_cd_day_label.setValue(cddLabel.c_str(), 16);
    para_cd_day_date.setValue(cddDate.c_str(), 8);
    para_tag_days.setValue(tagDays.c_str(), 30);
    para_si_week_1st.setValue(week1st.c_str(), 1);
    para_study_schedule.setValue(studySchedule.c_str(), 4000);

    wm.setTitle("J-Calendar");
    wm.addParameter(&para_si_week_1st);
    wm.addParameter(&para_qweather_host);
    wm.addParameter(&para_qweather_key);
    wm.addParameter(&para_qweather_type);
    wm.addParameter(&para_qweather_location);
    wm.addParameter(&para_cd_day_label);
    wm.addParameter(&para_cd_day_date);
    wm.addParameter(&para_tag_days);
    wm.addParameter(&para_study_schedule);
    // std::vector<const char *> menu = {"wifi","wifinoscan","info","param","custom","close","sep","erase","update","restart","exit"};
    std::vector<const char*> menu = { "wifi","param","update","sep","info","restart","exit" };
    wm.setMenu(menu); // custom menu, pass vector
    wm.setConfigPortalBlocking(false);
    wm.setBreakAfterConfig(true);
    wm.setPreSaveParamsCallback(preSaveParamsCallback);
    wm.setSaveParamsCallback(saveParamsCallback);
    wm.setSaveConnect(false); // 保存完wifi信息后是否自动连接，设置为否，以便于用户继续配置param。
    wm.startConfigPortal("J-Calendar", "password");

    led_config(); // LED 进入三快闪状态

    // 控制配置超时180秒后休眠
    _idle_millis = millis();
}

// 重置系统，并重启
void buttonLongPressStop(void* oneButton) {
    Serial.println("Button long press.");

    // 删除Preferences，namespace下所有健值对。
    Preferences pref;
    pref.begin(PREF_NAMESPACE);
    pref.clear();
    pref.end();

    ESP.restart();
}

#define uS_TO_S_FACTOR 1000000
#define TIMEOUT_TO_SLEEP  10 // seconds
time_t blankTime = 0;
void go_sleep() {
    uint64_t p;
    // 根据配置情况来刷新，如果未配置qweather信息，则24小时刷新，否则每2小时刷新
    Preferences pref;
    pref.begin(PREF_NAMESPACE);
    String _qweather_key = pref.getString(PREF_QWEATHER_KEY, "");
    pref.end();

    time_t now;
    time(&now);
    struct tm local;
    localtime_r(&now, &local);
    if (_qweather_key.length() == 0 || weather_type() == 0) { // 没有配置天气或者使用按日天气，则第二天刷新。
        // Sleep to next day
        int secondsToNextDay = (24 - local.tm_hour) * 3600 - local.tm_min * 60 - local.tm_sec;
        Serial.printf("Seconds to next day: %d seconds.\n", secondsToNextDay);
        p = (uint64_t)(secondsToNextDay);
        p = p < 0 ? 3600 * 24 : (p + 30); // 额外增加30秒，避免过早唤醒
    } else {
        // Sleep to next even hour.
        int secondsToNextHour = (60 - local.tm_min) * 60 - local.tm_sec;
        if ((local.tm_hour % 2) == 0) { // 如果是奇数点，则多睡1小时
            secondsToNextHour += 3600;
        }
        Serial.printf("Seconds to next even hour: %d seconds.\n", secondsToNextHour);
        p = (uint64_t)(secondsToNextHour);
        p = p < 0 ? 3600 : (p + 10); // 额外增加10秒，避免过早唤醒
    }

    esp_sleep_enable_timer_wakeup(p * (uint64_t)uS_TO_S_FACTOR);
    esp_sleep_enable_ext0_wakeup(KEY_M, LOW);

    // 省电考虑，关闭RTC外设和存储器
    // esp_sleep_pd_config(ESP_PD_DOMAIN_RTC_PERIPH, ESP_PD_OPTION_OFF); // RTC IO, sensors and ULP, 注意：由于需要按键唤醒，所以不能关闭，否则会导致RTC_IO唤醒(ext0)失败
    esp_sleep_pd_config(ESP_PD_DOMAIN_RTC_SLOW_MEM, ESP_PD_OPTION_OFF); // 
    esp_sleep_pd_config(ESP_PD_DOMAIN_RTC_FAST_MEM, ESP_PD_OPTION_OFF);
    esp_sleep_pd_config(ESP_PD_DOMAIN_XTAL, ESP_PD_OPTION_OFF);
    esp_sleep_pd_config(ESP_PD_DOMAIN_RTC8M, ESP_PD_OPTION_OFF);

    gpio_deep_sleep_hold_dis(); // 解除所有引脚的保持状态
    
    // 省电考虑，重置gpio，平均每针脚能省8ua。
    // gpio_reset_pin(PIN_LED_R); // 减小deep-sleep电流
    gpio_reset_pin(SPI_CS); // 减小deep-sleep电流
    gpio_reset_pin(SPI_DC); // 减小deep-sleep电流
    gpio_reset_pin(SPI_RST); // 减小deep-sleep电流
    gpio_reset_pin(SPI_BUSY); // 减小deep-sleep电流`
    gpio_reset_pin(SPI_MOSI); // 减小deep-sleep电流
    gpio_reset_pin(SPI_MISO); // 减小deep-sleep电流
    gpio_reset_pin(SPI_SCK); // 减小deep-sleep电流
    // gpio_reset_pin(PIN_ADC); // 减小deep-sleep电流
    // gpio_reset_pin(I2C_SDA); // 减小deep-sleep电流
    // gpio_reset_pin(I2C_SCL); // 减小deep-sleep电流

    delay(10);
    Serial.println("Deep sleep...");
    Serial.flush();
    esp_deep_sleep_start();
}

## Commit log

2025-09-01 修复闰年计算逻辑错误
2026-02-10 增加感谢名单
    [E-ink box2 v22.3mf]
